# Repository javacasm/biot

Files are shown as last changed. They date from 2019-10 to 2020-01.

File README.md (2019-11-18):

# Biot v1.3

Sistema de monitorización de un sistema biológico

Basado en los trabajos de Eulogio (https://github.com/inopya/biot) y más detallado en (https://github.com/inopya/mini-tierra)

Licencia CC para la documentación

Licencia CC

[Licencia GPL](./LICENSE) para el código

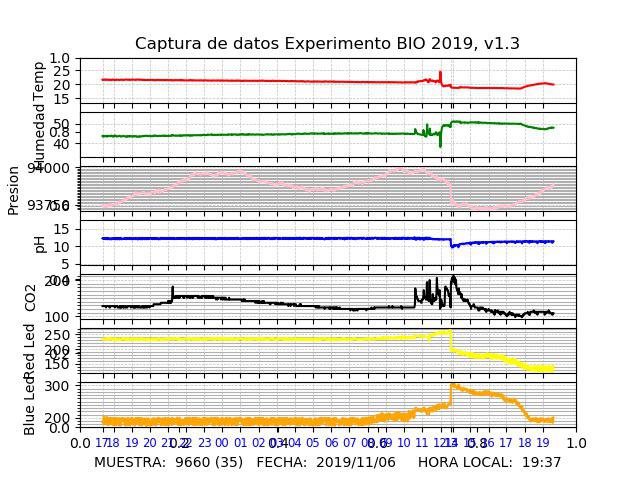
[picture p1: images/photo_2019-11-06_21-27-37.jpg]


## Montaje

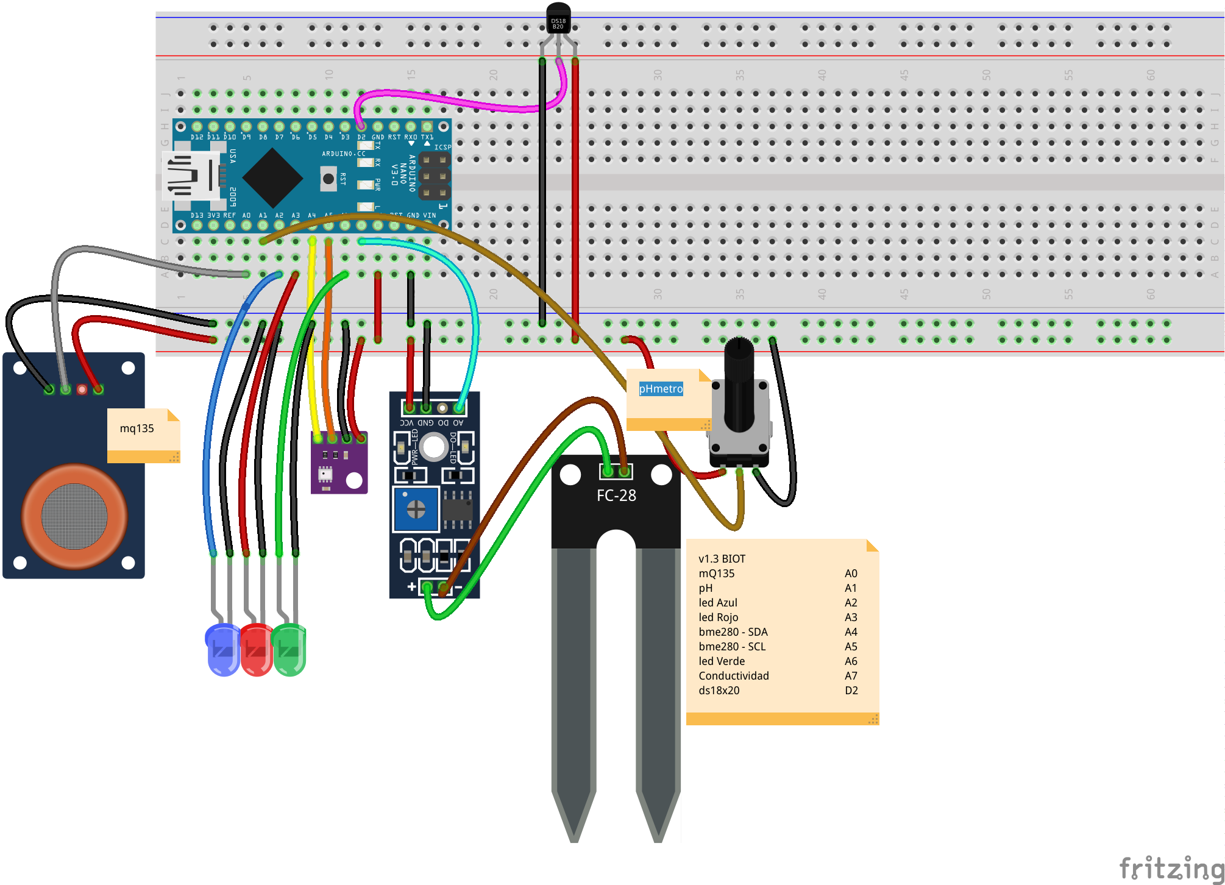
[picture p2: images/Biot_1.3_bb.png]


	mQ135		A0
	pH 			A1
	led Azul		A2
	led Rojo		A3
	bme280 - SDA	A4 
	bme280 - SCL	A5
	led Verde		A6
	Conductividad	A7
	ds18x20		D2

Arduino nano

Arduino nano pinout

### Sensor atomosferico BME280

#### Cambio de address



[Documentacion BME280](https://lastminuteengineers.com/bme280-arduino-tutorial/)

Podemos usar 2 BME280 desde la API de la librer'ia de adafruit [Ejemplo](https://github.com/adafruit/Adafruit_BME280_Library/blob/master/Adafruit_BME280.h#L133) usando begin(address)

## Código

Actualizado el fichero biodata.py a version 1.3
* Soporta 7 dato de presion atmósferica
* Optimizado el repintado para no cargar el sistema a 1 vez por minuto
* Dibujando los 7 valores

Actualizado biot_1.1.ino
* Permite elegir entre el sensor Gy-21 y el bme280 que mide también la presión atmosférica

Añadido calibracion_ph.ino
* Para calibrar el sensor de pH

Actualizado el fichero biodata.py a version 1.2

* Se han agrupado todos los datos que deben ser configurados por el usuario para mayor comodidad.

* (Si ejecutas esta nueva versión recuerda utilizar el comando /start en tu bot para reiniciarlo y poder ver las nuevas opciones en el menu. en cualquier caso, escribiendolas estaran disponibles).
* Añadidos tres nuevos comandos al menu del bot:
  * /txt  envia el fichero de datos como mensaje de telegram.
  * /deleteOld  borra los primeros 15 datos de la serie, de manera que se pueden ir eliminando los datos erroneos de los primeros minutos.
  * /deleteNew  borra los ultimos 15 datos de la serie, de manera que se pueden ir eliminando posibles datos erroneos de los ultimos minutos.
* Se ha suprimido la representacion de dos variables (luz roja y luz azul) ya que no se conectaron y solo mostraban ruido.
* Se han separado las graficas de temperatura y humedad para que se muestren mejor en sus respectivas escalas.
* Modificada la funcion de representacion grafica para que solo represente como maximo 1440 muestras. Es decir las ultimas 24 horas, si se toma una muestra por minuto. Pero la toma de datos si conserva todos y seran enviados cuando se pida el txt o el email

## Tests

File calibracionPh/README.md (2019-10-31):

# Calibrado del sensor de pH
* Sin conectar la sonda, cortocircuitamos los terminales y ajustamos la medida de A0 a 2.5v moviendo el potenciometro más cercano a la sonda. En mi caso no llegó a bajar de 2.7v
* Conectamos la sonda y ajustamos el valor de la medida para dos pHs conocidos. Por ejemplo vinagre 3.4 y agua del grifo 8

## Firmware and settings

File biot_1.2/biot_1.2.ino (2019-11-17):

/*
#       _\|/_   A ver..., ¿que tenemos por aqui?
#       (O-O)        
# ---oOO-(_)-OOo---------------------------------
 
 
##########################################################
# ****************************************************** #
# *          LABORATORIO PARA PRINCIPIANTES            * #
# *     Experimentos para el Biotecnoencuentro 3       * #
# *          Autor:  Eulogio López Cayuela             * #
# *         Errores:  Javacasm                         * #
# *                                                    * #
# *     Experimento Bio v1.3     Fecha: 09/11/2019     * #
# ****************************************************** #
##########################################################
*/


#define __VERSION__ "Experimento Biotecnoencuentro 3 v1.3"

#define USE_BME280 1
#define USE_LCDI2C 1

/*
      ===== NOTAS DE LA VERSION "ZANGANO" ===== 
 - Version minimalista que pasa todo el trabajo al software python
   y que se limita a servir de interfaz para la adquisicion de datos

 - se han renombrado algunas cosas para mas claridad

   >> Fecha: 11/05/2019
 - Calibrado del sensor de gases MQ135 para usarlo con CO2
   Se realiza la calibracion ante un entorno cpn concentracion conocida.
   (Usaremos alrededor de  415ppm que es lo que se estima de media ahora mismpo en el planeta)
   
   Tamaño actual compilado 7864 bytes de programa y 444 bytes de uso de RAM

    a = 5.5973021420;
    b = -0.365425824;
    Ro=(Rs/a*(ppm)pow(b))
    Rs = Rsensor_media
    Rsensor_media= (Sumatorio(n) Rs )/n   // n muestras durante 5 minutos cada 1 segundos
    Rs = 1024 * (RL/acd)-RL  <<<  RL = 20k(20000)


    Anadida la posibilidad de usar el sensor BME280 que mide presion sustituyendo al GY-21

  CONEXIONES:
 =======================
  ARDUINO UNO      MQ-135
 =======================
  GND               GND
  5V                Vcc
  A0                A0


 =======================
  ARDUINO UNO      GY-21
 =======================
  GND               GND
  5V                Vin
  SCL (A5)          SCL
  SDA (A4)          SDA



 =======================
  ARDUINO UNO      BME280
 =======================
  GND               GND
  5V                Vin
  SCL (A5)          SCL
  SDA (A4)          SDA


  CONEXIONES:
 =======================
  ARDUINO UNO   SENSOR PH
 =======================
  GND               GND
  5V                Vcc
  A1                P0


 =======================
  ARDUINO        LEDS
 =======================
  GND         GND de los leds

  A2          led AZUL
  A3          led ROJO
  A6          led Verde

 =======================
  ARDUINO     Sensor de conductividad/humedad
 =======================
  GND         GND 
  5V          Vcc
  A7          A0

  
 =======================
  ARDUINO     DS18x20
 =======================
  GND         GND 
  5V          Vcc
  OUT         D2

  

*/




/*mmmmmmmmmmmmmmmmmmmmmmmmmmmmmmmmmmmmmmmmmmmmmmmmmmmmmmmmmmmmmmmmmmmmmmmmmmmmmmmmmmmmmmmmmmmmmmmmmmm
//        IMPORTACION DE LIBRERIAS 
//mmmmmmmmmmmmmmmmmmmmmmmmmmmmmmmmmmmmmmmmmmmmmmmmmmmmmmmmmmmmmmmmmmmmmmmmmmmmmmmmmmmmmmmmmmmmmmmmmmm*/
#include <Wire.h>
#ifdef USE_BME280
#include <BME280I2C.h>
#else
#include <Adafruit_HTU21DF.h>  //ojo esta libreria tal cual falla(fallo gordo), la he retocado
//queda pendiente escribir una propia
#endif

#ifdef USE_LCDI2C
#include <LiquidCrystal_I2C.h>
#endif


/*mmmmmmmmmmmmmmmmmmmmmmmmmmmmmmmmmmmmmmmmmmmmmmmmmmmmmmmmmmmmmmmmmmmmmmmmmmmmmmmmmmmmmmmmmmmmmmmmmmm
//        CREACCION DE OBJETOS
//mmmmmmmmmmmmmmmmmmmmmmmmmmmmmmmmmmmmmmmmmmmmmmmmmmmmmmmmmmmmmmmmmmmmmmmmmmmmmmmmmmmmmmmmmmmmmmmmmmm*/

#ifdef USE_BME280
BME280I2C bme;
#else
Adafruit_HTU21DF Higrometro_GY_21 = Adafruit_HTU21DF();
#endif


#ifdef USE_LCDI2C
LiquidCrystal_I2C lcd(0x27,20,4);  // set the LCD address to 0x27 for a 16 chars and 2 line display
#endif
/*mmmmmmmmmmmmmmmmmmmmmmmmmmmmmmmmmmmmmmmmmmmmmmmmmmmmmmmmmmmmmmmmmmmmmmmmmmmmmmmmmmmmmmmmmmmmmmmmmmm
//        SECCION DE DECLARACION DE CONSTANTES  Y  VARIABLES GLOBALES
//mmmmmmmmmmmmmmmmmmmmmmmmmmmmmmmmmmmmmmmmmmmmmmmmmmmmmmmmmmmmmmmmmmmmmmmmmmmmmmmmmmmmmmmmmmmmmmmmmmm*/

//------------------------------------------------------------------------
// Algunas definiciones personales para mi comodidad al escribir codigo
//------------------------------------------------------------------------
#define AND &&
#define OR ||
#define NOT !
#define ANDbit &
#define ORbit |
#define NOTbit ~
#define XORbit ^


//------------------------------------------------------
//Otras definiciones para pines y variables
//------------------------------------------------------
#define PIN_LED_OnBoard    13   // Led on Board

#define PIN_MQ135          A0
#define PIN_SENSOR_PH      A1

#define PIN_led_azul       A2 
#define PIN_led_rojo       A3
#define PIN_led_verde      A6

#define PIN_Sensor_Humedad A7

#define PIN_DS18x20         2
 
float TEMPERATURA = -100;   //inicializado fuera de rango
float HUMEDAD = -100;       //inicializado fuera de rango
float PRESION = -100;       //inicializado fuera de rango
int PPM = -100;             //inicializado fuera de rango
float PH = -100;            //inicializado fuera de rango
int LUZ_AZUL = -100;        //inicializado fuera de rango
int LUZ_ROJA = -100;        //inicializado fuera de rango
  
unsigned long momento_para_adquirir_datos = 0;  //para controlar el momento de tomar muestras

boolean FLAG_calibracion = false;

float a = 5.5973021420;         //a y b   constantes del sensor para medidas de CO2
float b = -0.365425824;         //obtenidas de su hoja de caracteristicas

unsigned long Ro = 221541;      //Ro  del sensor que se ha de calcular calibrandolo. 
                                //Se usa este valor si no se activa la calibracion
#define PPM_REFERENCIA  410     //ppm del ambiente de calibracion

#ifdef USE_LCDI2C
  #define mostrarMensaje(x) Serial.println(x); lcd.print(x);
#else  
  #define mostrarMensaje(x) Serial.println(x); 
#endif

/*mmmmmmmmmmmmmmmmmmmmmmmmmmmmmmmmmmmmmmmmmmmmmmmmmmmmmmmmmmmmmmmmmmmmmmmmmmmmmmmmmmmmmmmmmmmmmmmmmmmmmmmm
   ****************************************************************************************************** 
                                    FUNCION DE CONFIGURACION
   ****************************************************************************************************** 
//mmmmmmmmmmmmmmmmmmmmmmmmmmmmmmmmmmmmmmmmmmmmmmmmmmmmmmmmmmmmmmmmmmmmmmmmmmmmmmmmmmmmmmmmmmmmmmmmmmmmmmmm*/

void setup()
{
  Serial.begin(115200);               //#9600, 19200, 38400, 57600, 115200
  delay(1000);
  Serial.println (F(__VERSION__));    // mostramos la version por consola, DEBUG

#ifdef USE_LCDI2C
  lcd.init();
  lcd.backlight();
  lcd.print(F(__VERSION__));
#endif
  
#ifdef USE_BME280
  Wire.begin();
  if (!bme.begin()) {
    mostrarMensaje(F("Sensor BME no detectado"));
  }
#else
  if (!Higrometro_GY_21.begin()) {
        mostrarMensaje(F("Sensor HT no presente"));
    //while (true);  //saltamos este punto porque sensores clon no responden correctamente
  }
#endif    


  pinMode(PIN_LED_OnBoard, OUTPUT);   // PIN_LED_OnBoard como salida
  digitalWrite(PIN_LED_OnBoard, LOW); // apagamos el led 'On Board'

  if (FLAG_calibracion == true){
    Ro = calibrarCO2();
  }
  
  leerSensores();     //refresco inicial de las variables
}



/*mmmmmmmmmmmmmmmmmmmmmmmmmmmmmmmmmmmmmmmmmmmmmmmmmmmmmmmmmmmmmmmmmmmmmmmmmmmmmmmmmmmmmmmmmmmmmmmmmmmmmmmm
   ****************************************************************************************************** 
                                  BUCLE PRINCIPAL DEL PROGRAMA
   ****************************************************************************************************** 
//mmmmmmmmmmmmmmmmmmmmmmmmmmmmmmmmmmmmmmmmmmmmmmmmmmmmmmmmmmmmmmmmmmmmmmmmmmmmmmmmmmmmmmmmmmmmmmmmmmmmmmmm*/

void loop()
{ 
  /* mostrar medidas resales en funcion de la calibracion */
  unsigned long momento_actual = millis();
  if (momento_actual > momento_para_adquirir_datos){
    momento_para_adquirir_datos = momento_actual + 5000;    //una muestra cada 5 segundos
    leerSensores();
    //mostarDatosEnPython(); //si deseamos monitorizar solo en puerto serie
  }
  leerPuertoSerie();  //mostraremos los datos solo si hay peticiones por puerto serie
}



/*mmmmmmmmmmmmmmmmmmmmmmmmmmmmmmmmmmmmmmmmmmmmmmmmmmmmmmmmmmmmmmmmmmmmmmmmmmmmmmmmmmmmmmmmmmmmmmmmmmmmmmmm
   ###################################################################################################### 
        BLOQUE DE FUNCIONES: LECTURAS DE SENSORES, COMUNICACION SERIE, CONTROL LCD...
   ###################################################################################################### 
//mmmmmmmmmmmmmmmmmmmmmmmmmmmmmmmmmmmmmmmmmmmmmmmmmmmmmmmmmmmmmmmmmmmmmmmmmmmmmmmmmmmmmmmmmmmmmmmmmmmmmmmm*/

/*mmmmmmmmmmmmmmmmmmmmmmmmmmmmmmmmmmmmmmmmmmmmmmmmmmmmmmmmmmmmmmmmmmmmmmmmmmmmmmmmmmmmmmmmmmmmmmmmmmmmmmmm
//    RECOPILAR DATOS DE LOS SENSORES
//mmmmmmmmmmmmmmmmmmmmmmmmmmmmmmmmmmmmmmmmmmmmmmmmmmmmmmmmmmmmmmmmmmmmmmmmmmmmmmmmmmmmmmmmmmmmmmmmmmmmmmmm*/

//========================================================
//  FUNCION OBTENER DATOS DESDE LOS SENSORES
//========================================================

void leerSensores()
{ 
#ifdef USE_BME280
   BME280::TempUnit tempUnit(BME280::TempUnit_Celsius);
   BME280::PresUnit presUnit(BME280::PresUnit_Pa);
   bme.read(PRESION, TEMPERATURA, HUMEDAD, tempUnit, presUnit);   
#else 
  /* leer datos desde el sensor de humedad y temperatura  GY-21 - HTU21DF*/
  TEMPERATURA = Higrometro_GY_21.readTemperature();
  HUMEDAD = Higrometro_GY_21.readHumidity();
#endif  
  /* medir valor de PH */
  PH = medir_ph();
  
  /* lectura el CO2 desde el MQ135*/
  int adc = lecturaSensorMQ(PIN_MQ135);
  float Rsensor = (1024*(20000.0/adc))-20000;
  PPM = pow((Rsensor/Ro)/a,(1/b)); // 'a' y 'b', constantes del sensor. 'Ro',  valor calculado previamente

  /* medir luminosidad con los led*/
  LUZ_AZUL = analogRead(PIN_led_azul);
  LUZ_ROJA = analogRead(PIN_led_rojo);
  LUZ_VERDE = analogRead(PIN_led_verde);

  TEMPERATURA_AGUA = 

#ifdef USE_LCDI2C
  mostarDatosEnLCD();
#endif
}


/*mmmmmmmmmmmmmmmmmmmmmmmmmmmmmmmmmmmmmmmmmmmmmmmmmmmmmmmmmmmmmmmmmmmmmmmmmmmmmmmmmmmmmmmmmmmmmmmmmmmmmmmm
//    MQ135
//mmmmmmmmmmmmmmmmmmmmmmmmmmmmmmmmmmmmmmmmmmmmmmmmmmmmmmmmmmmmmmmmmmmmmmmmmmmmmmmmmmmmmmmmmmmmmmmmmmmmmmmm*/

//========================================================
//  FUNCION PARA CALIBRAR EL MQ135 PARA CO2
//========================================================

unsigned long calibrarCO2()
{          
  float Rsensor_media = 0;   //variable usada para la calibracion
  int iteraciones  = 0;
  unsigned long inicio = millis();
  
  mostrarMensaje(F("Calibrando Sensor..."));
  
  while(millis()-inicio < 300000){  //5 minutos aproximadamente
    int adc = lecturaSensorMQ(PIN_MQ135);
    float Rsensor = (1024*(20000.0/adc))-20000;
    Rsensor_media += Rsensor;
    iteraciones++;
    delay(1000);
    Serial.print(F("."));
    if(iteraciones%30==0){
      Serial.println();
    }
  }
  mostrarMensaje(F("  OK"));

  /* calculo de Ro en funcion de la Rs media durante 5 minutos a una concentracion de CO2 conocida */
  Rsensor_media /= iteraciones;

  unsigned long ro = Rsensor_media/(a*pow(PPM_REFERENCIA, b));  //ppm=410 ( ¿la media mundial actual? )

  /* mostrar los datos calculados */
  mostrarMensaje(F("Ro = "));mostrarMensaje(ro);
  Serial.println("");
  return ro;
}


//========================================================
//  FUNCION PARA OBTENER LECTURAS DEL ADC DE UN MQxxx
//========================================================

int lecturaSensorMQ(uint8_t pin)
{
  /* hacemos el promedio de 8 muestras consecutivas */
  int analogica_MQ = 0;
  for(int i=0;i<8;i++){  //leemos 8 veces y hacemos la media
    analogica_MQ += analogRead(pin);
    delay(2);
  }
  analogica_MQ = analogica_MQ >> 3; // division por 8 (con desplazamiento de 3 bits)        
  return analogica_MQ; 
}


/*mmmmmmmmmmmmmmmmmmmmmmmmmmmmmmmmmmmmmmmmmmmmmmmmmmmmmmmmmmmmmmmmmmmmmmmmmmmmmmmmmmmmmmmmmmmmmmmmmmmmmmmm
//    SENSOR DE PH
//mmmmmmmmmmmmmmmmmmmmmmmmmmmmmmmmmmmmmmmmmmmmmmmmmmmmmmmmmmmmmmmmmmmmmmmmmmmmmmmmmmmmmmmmmmmmmmmmmmmmmmmm*/

//========================================================
//  OBTENER DATOS DESDE EL SENSOR ANALOGICO DE PH
//========================================================

float medir_ph() 
{
  int buffer_lecturas[10];
  int temp;
  
  /* toma de muestras */
  for(int i=0;i<10;i++) { 
    buffer_lecturas[i] = analogRead(PIN_SENSOR_PH);
    delay(100);
  }
  
  /* ordenar las muestas de menor a mayor */
  for(int i=0;i<9;i++){
    for(int j=i+1;j<10;j++){
      if(buffer_lecturas[i]>buffer_lecturas[j]){
        temp=buffer_lecturas[i];
        buffer_lecturas[i]=buffer_lecturas[j];
        buffer_lecturas[j]=temp;
      }
    }
  }

  /* calcular el valor medio despreciando los dos valores menores y los dos mayores */
  float valor_medio = 0; 
  for(int i=2;i<8;i++){
    valor_medio+=buffer_lecturas[i];
  }

  valor_medio = valor_medio/6;

  /* obtener el voltage asociado a la lectura del pin analogico (sin utilidad por ahora) */
  //float Vph = valor_medio*5.0/1023;  

  /* ---  calculo del PH usando dos medidas de ph conocidas para calibrar --- */
  float ph_bajo = 3.4;        // Vinagre, ph = 3.4
  float adc_ph_bajo = 740;    // valor ADC para ph = 3.4          (ph obtenidos con papel tornasol)

  
  float ph_alto = 8;          // Agua del grifo, ph = 8
  float adc_ph_alto = 640;    // valor ADC para ph = 8  
  
  float PH2 = (valor_medio - adc_ph_alto ) * ((ph_alto-ph_bajo) / ( adc_ph_alto - adc_ph_bajo )) + ph_alto;

  if(PH2>=0 AND PH2<=14){
    //Serial.print(F("PH = "));
    //Serial.println(PH2, 2);
  }
  else{
    //Serial.println(F("ERROR - Revise la sonda"));
   // PH2 = -100;
  }
  return PH2;
}

/*mmmmmmmmmmmmmmmmmmmmmmmmmmmmmmmmmmmmmmmmmmmmmmmmmmmmmmmmmmmmmmmmmmmmmmmmmmmmmmmmmmmmmmmmmmmmmmmmmmmmmmmm
//    PUERTO SERIE
//mmmmmmmmmmmmmmmmmmmmmmmmmmmmmmmmmmmmmmmmmmmmmmmmmmmmmmmmmmmmmmmmmmmmmmmmmmmmmmmmmmmmmmmmmmmmmmmmmmmmmmmm*/

//========================================================
// FUNCION PARA ACCESO Y LECTURA DEL PUERTO SERIE
//========================================================

int leerPuertoSerie()
  /*
  Funcion para atender ordenes a través del puerto serie
  Lee los comandos/parametros que envia python al puerto serie:
  
  - Si el comandos es '*' se realiza una muestra unica de datos
  - Si el comandos es 'x' ordena que cancele el proceso de muestreo y envio de datos
  ---- (Ampliable en un futuro para mas cosas
  */
  
{
  int lectura = 'x';                //por defecto pensamos que no se nos pide nada
  if (Serial.available() > 0) {
     // leer byte
    lectura = Serial.read();
    if (lectura == '*' OR lectura == '+'){  // indicador para mandar una muestra unica al puerto serie
      mostarDatosEnPython();
      return 0;  //ok, peticion de datos
     } 
  }
  return -1;    //sin peticion por parte del usuario
}


//========================================================
//  ENVIAR DATOS POR PUERTO SERIE A PYTHON
//========================================================

void mostarDatosEnPython()
{ 
  Serial.flush();
  
  /* FORMATEO de datos y ENVIO al puerto SERIE */
  Serial.print(TEMPERATURA);
  Serial.print(F("**"));
  Serial.print(HUMEDAD);
  Serial.print(F("**"));
  Serial.print(PH);
  Serial.print(F("**"));
  Serial.print(PPM);
  Serial.print(F("**"));
  Serial.print(LUZ_AZUL);
  Serial.print(F("**"));
  Serial.print(LUZ_ROJA); 
  Serial.print(F("**"));
  Serial.println(PRESION);
  
}


#ifdef USE_LCDI2C
//========================================================
//  ENVIAR DATOS EN LCD
//========================================================

void mostarDatosEnLCD()
{ 
  lcd.clear();
  
  /* FORMATEO de datos y ENVIO al puerto SERIE */
  lcd.setCursor(0,0);
  lcd.print(F("T:"));
  lcd.print(TEMPERATURA);
  lcd.print(F("C H:"));
  lcd.print(HUMEDAD);
  lcd.print(F("%"));

  lcd.setCursor(0,1);
  lcd.print(F("P:"));
  lcd.print(PRESION);
  lcd.print(F("atm"));
  lcd.setCursor(0,2);
  lcd.print(F("PH:"));
  lcd.print(PH);
  

  lcd.print(F(" CO2:"));
  lcd.print(PPM);
  
  lcd.setCursor(0,3);
  lcd.print(F("Azul:"));
  lcd.print(LUZ_AZUL);
  lcd.print(F(" Roja:"));
  lcd.print(LUZ_ROJA); 
}

#endif

//*******************************************************
//                    FIN DE PROGRAMA
//*******************************************************

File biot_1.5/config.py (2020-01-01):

# Configuracion

import os               #manejo de funciones del sistema operativo 

# v1.5


'''***********************************************************************************************'''
'''***********************************************************************************************'''
'''***********************************************************************************************'''

#    IMPORTANTE, DATOS A CONFIGURAR POR EL USUARIO    #

'''***********************************************************************************************'''

#DATOS DEL SERVIDOR DE CORREO PARA REALIZAR LOS ENVIOS
#ojo, aqui estaran visibles la direccion y la contraseña :(  (Recuerdado a la hora de pasar el codigo a alguien)
#Las cuentas de gmail deberan configurarse para que admitan "dispositivos no seguros" 

SMTP_CORREO_ENVIOS = 'smtp.yandex.com'
EMAIL_CORREO_ENVIOS = 'biotecnoencuentro2019@yandex.com'
PASS_CORREO_ENVIOS = 'srgmbvdnahchrwjv'
REMITENTE_CORREO_ENVIOS = 'biotecnoencuentro2019@yandex.com'  #yandex no permite otro remitente que no sea la direccion de salida
                                                              #si usais gmail como smtp, podeis poner una cadena de texto a vuestro gusto :)

#lista de direcciones de correo a la que se enviaran los datos del experimento. Necesaria al menos una direccion.
lista_correo_experimento = ['javacasm@gmail.com']      #quitar esta y poner la vuestra


#CLAVE para la API de telegram (token del bot)
TOKEN = "892980687:AAEAr6zBV5GDFoGKhxzEjzz-yUMPmvNRV1Y" # quitar este y poner el de vuestro bot


# Definimos la id del que sera el usuarios administrador y que dispondra de derechos de uso completo
# (podemos definir otros usuarios que no tengan acceso total)

ADMIN_USER = None  #None: todos los que se conectan pueden realizar: - el envio de correo a la lista de autorizados
                   #                                                 - el salvado manual de datos
                   #                                                 - el borrado de datos
                   #Si establecemos un numero ID de telegram, solo el usuario con ese numero ID puede realizar esos tres comandos


ID_ESTACION_BIO = "BIO_JAVACASM"   # este ID se incorpora a los mensajes de informacion
                                 #y a las muestras de datos del fichero txt (sustituirla por algo personal)

TIEMPO_ENTRE_MUESTRAS = 60 # tiempo en segundos. Por defecto 60, un minuto




'''***********************************************************************************************'''
'''***********************************************************************************************'''
'''***********************************************************************************************'''

ruta_programa = os.path.dirname(os.path.abspath(__file__)) +'/'

RUTA_BACKUP = ''  #RUTA_BACKUP = 'backup/'

FICHERO_DATOS_EXPERIMENTO = 'experimento_bio.dat'
FICHERO_TXT_EXPERIMENTO = 'experimento_bio.txt'
FICHERO_GRAFICA_EXPERIMENTO = 'experimento_bio.png'


SerialDelay = 0.5                   #tiempo entre llamadas del puerto (en segundos), para que pueda reaccionar.
                                    #No usar tiempos inferiores a 0.25 segundos 
VELOCIDAD_PUERTO_SERIE = 115200

INTERVALO_BACKUP = 10               #intervalo en minutos para copias de seguridad

# MQTT configuration

MQTT_SERVER = '192.168.1.200'

BaseTopic_sub = 'MeteoSalon'
